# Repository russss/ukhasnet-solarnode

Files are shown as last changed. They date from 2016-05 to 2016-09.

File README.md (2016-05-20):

# UKHASnet SolarNode

A [ukhasnet node](https://ukhas.net) implementation designed for use as
a remote, solar/lithium battery-powered repeater.

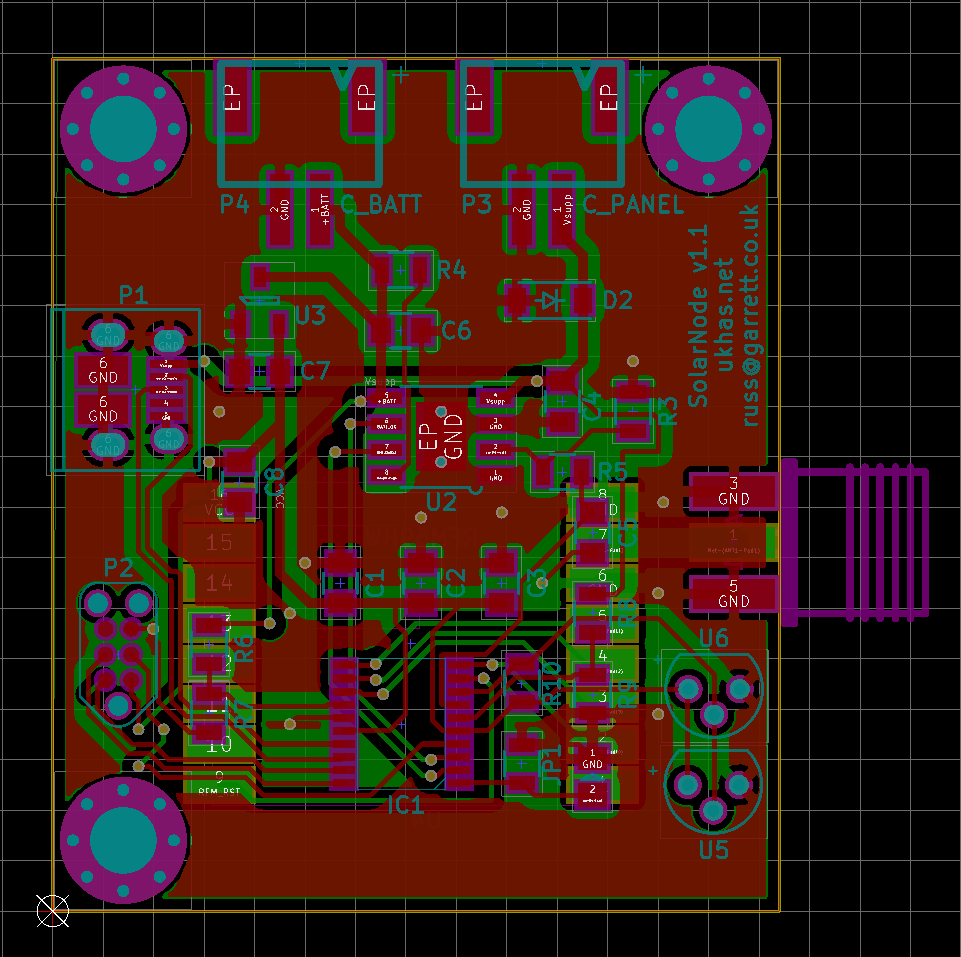
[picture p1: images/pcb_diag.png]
PCB layout


## Features

* STM32 ARM micoprocessor
* CN3083 Li-Ion charge controller
* RFM89[H][W] radio
* Charging and configuration over USB
* Comprehensive battery telemetry:
    * Supply (solar panel) voltage
    * Battery voltage
    * Charge current
    * Charger status
* Breakout for one-wire sensors

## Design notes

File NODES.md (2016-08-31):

* 1: Initial dev board, RFM69W. CN3083 potentially damaged by
     overvolting.
* 2: RFM69HW.

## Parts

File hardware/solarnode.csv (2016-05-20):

Reference | Value | Footprint | Datasheet | Farnell
P2 | TC2030-CTX | Tag-Connect:TC2030-NL_SMALL
U4 | RFM69HW | tinkerforge:RFM69HW
ANT1 | ANT | tinkerforge:CON-SMA-EDGE
P1 | USB_OTG | Connect:USB_Micro-B_10103594-0001LF
P3 | C_PANEL | tinkerforge:JST-PH-2
P4 | C_BATT | tinkerforge:JST-PH-2
D2 | 6V | Diodes_SMD:SOD-123
R8 | 10k | Resistors_SMD:R_0805
R9 | 10k | Resistors_SMD:R_0805
C4 | 22u | Capacitors_SMD:C_0805
R3 | 3k6 | Resistors_SMD:R_0805
R5 | 10k | Resistors_SMD:R_0805
C5 | C | Capacitors_SMD:C_0805
R4 | 0 | Resistors_SMD:R_0805
U3 | MCP1700 | agg:SOT-23
C7 | 1u | Capacitors_SMD:C_0805
R6 | 4k7 | Resistors_SMD:R_0805
R7 | 10k | Resistors_SMD:R_0805
R10 | 4k7 | Resistors_SMD:R_0805
C8 | 100n | Capacitors_SMD:C_0805
C2 | 100n | Capacitors_SMD:C_0805
C3 | 100n | Capacitors_SMD:C_0805
C1 | 4.7u | Capacitors_SMD:C_0805
JP1 | Boot | Resistors_SMD:R_0805
D1 | Status | agg:0805-LED
U5 | DS18B20 | TO_SOT_Packages_THT:TO-92_Molded_Narrow
U6 | DS18B20 | TO_SOT_Packages_THT:TO-92_Molded_Narrow
C6 | 4.7u | Capacitors_SMD:C_0805
IC1 | STM32F0xxFxPx | tinkerforge:TSSOP20 | http://www.st.com/st-web-ui/static/active/en/resource/technical/document/datasheet/DM00105814.pdf | 2469549
U2 | CN3083 | agg:SOIC-8-EP-CN

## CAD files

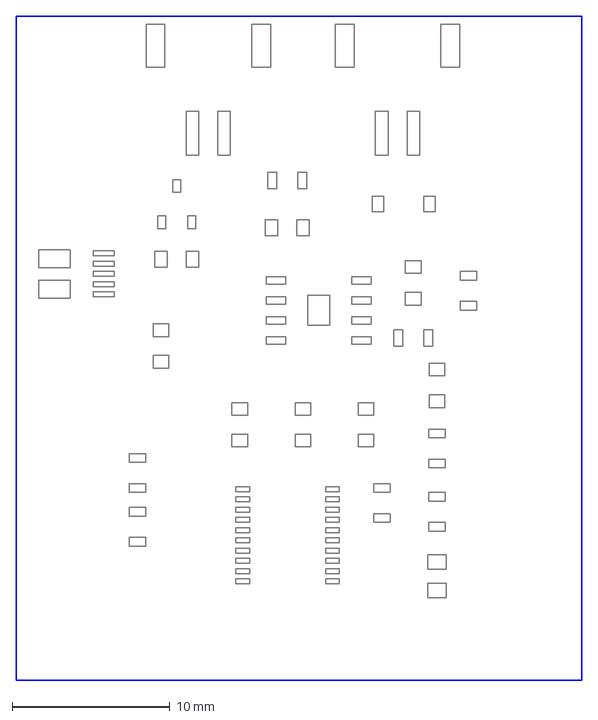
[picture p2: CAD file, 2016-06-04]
hardware/stencil.dxf
35.8 x 42.1 mm

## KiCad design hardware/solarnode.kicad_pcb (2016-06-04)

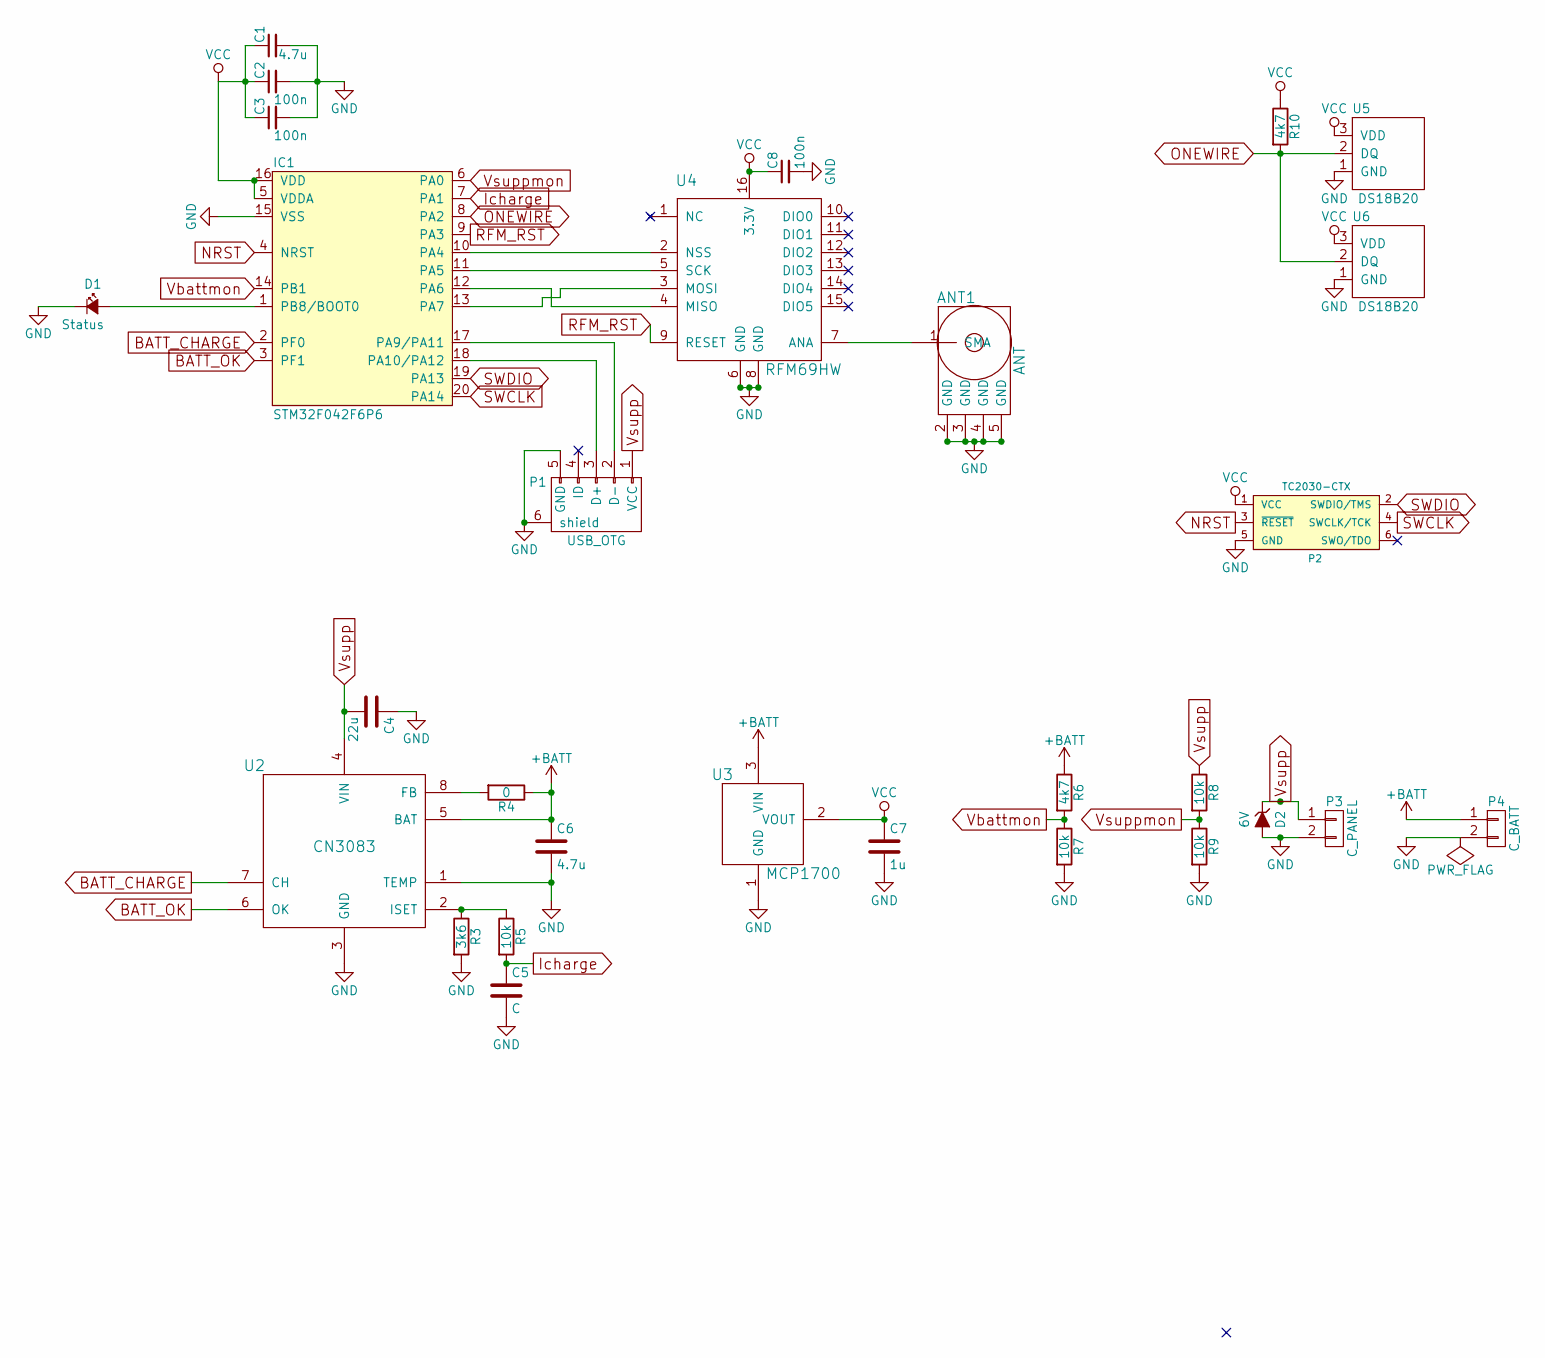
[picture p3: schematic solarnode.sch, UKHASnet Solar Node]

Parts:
ANT1: ANT; CON-SMA-EDGE
C1, C6: 4.7u; C_0805
C2, C3, C8: 100n; C_0805
C4: 22u; C_0805
C5: C; C_0805
C7: 1u; C_0805
D1: Status; 0805-LED
D2: 6V; SOD-123
IC1: STM32F042F6P6; TSSOP20; Farnell 2469549
P1: USB_OTG; USB_Micro-B_10103594-0001LF
P2: TC2030-CTX; TC2030-NL_SMALL
P3: C_PANEL; JST-PH-2
P4: C_BATT; JST-PH-2
R3: 3k6; R_0805
R4: 0; R_0805
R5, R7, R8, R9: 10k; R_0805
R6, R10: 4k7; R_0805
U2: CN3083; SOIC-8-EP-CN
U3: MCP1700; SOT-23
U4: RFM69HW
U5, U6: DS18B20; TO-92_Molded_Narrow

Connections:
+BATT: C6.1, P4.1, R4.1, R6.1, U2.5 (BAT), U3.3 (VIN)
BATT_CHARGE: IC1.2 (PF0), U2.7 (CH)
BATT_OK: IC1.3 (PF1), U2.6 (OK)
GND: ANT1.2 (GND), ANT1.3 (GND), ANT1.4 (GND), ANT1.5 (GND), C1.2, C2.2, C3.2, C4.1, C5.2, C6.2, C7.2, C8.2, D1.1 (K), D2.2 (A), IC1.15 (VSS), P1.5 (GND), P1.6 (shield), P2.5 (GND), P3.2, P4.2, R3.2, R7.2, R9.2, U2.1 (TEMP), U2.3 (GND), U2.EP, U3.1 (GND), U4.6 (GND), U4.8 (GND), U5.1 (GND), U6.1 (GND)
Icharge: C5.1, IC1.7 (PA1), R5.2
NRST: IC1.4 (NRST), P2.3 (~RESET~)
unnamed: ANT1.1 (SMA), U4.7 (ANA)
unnamed: D1.2 (A), IC1.1 (PB8/BOOT0)
unnamed: IC1.10 (PA4), U4.2 (NSS)
unnamed: IC1.11 (PA5), U4.5 (SCK)
unnamed: IC1.12 (PA6), U4.4 (MISO)
unnamed: IC1.13 (PA7), U4.3 (MOSI)
unnamed: IC1.17 (PA9/PA11), P1.2 (D-)
unnamed: IC1.18 (PA10/PA12), P1.3 (D+)
unnamed: R3.1, R5.1, U2.2 (ISET)
unnamed: R4.2, U2.8 (FB)
ONEWIRE: IC1.8 (PA2), R10.2, U5.2 (DQ), U6.2 (DQ)
RFM_RST: IC1.9 (PA3), U4.9 (RESET)
SWCLK: IC1.20 (PA14), P2.4 (SWCLK/TCK)
SWDIO: IC1.19 (PA13), P2.2 (SWDIO/TMS)
VCC: C1.1, C2.1, C3.1, C7.1, C8.1, IC1.5 (VDDA), IC1.16 (VDD), P2.1 (VCC), R10.1, U3.2 (VOUT), U4.16 (3.3V), U5.3 (VDD), U6.3 (VDD)
Vbattmon: IC1.14 (PB1), R6.2, R7.1
Vsupp: C4.2, D2.1 (K), P1.1 (VCC), P3.1, R8.1, U2.4 (VIN)
Vsuppmon: IC1.6 (PA0), R8.2, R9.1

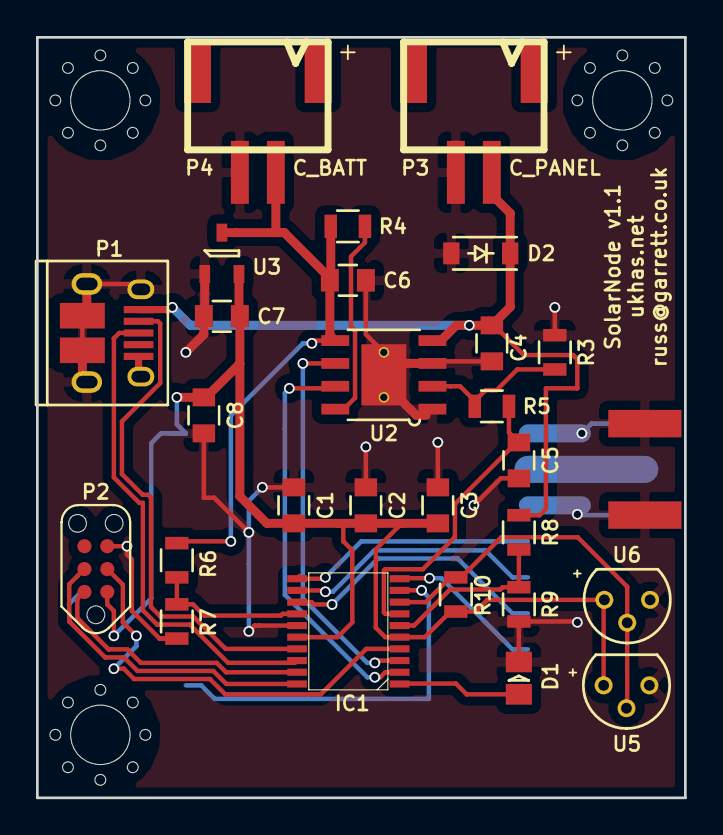
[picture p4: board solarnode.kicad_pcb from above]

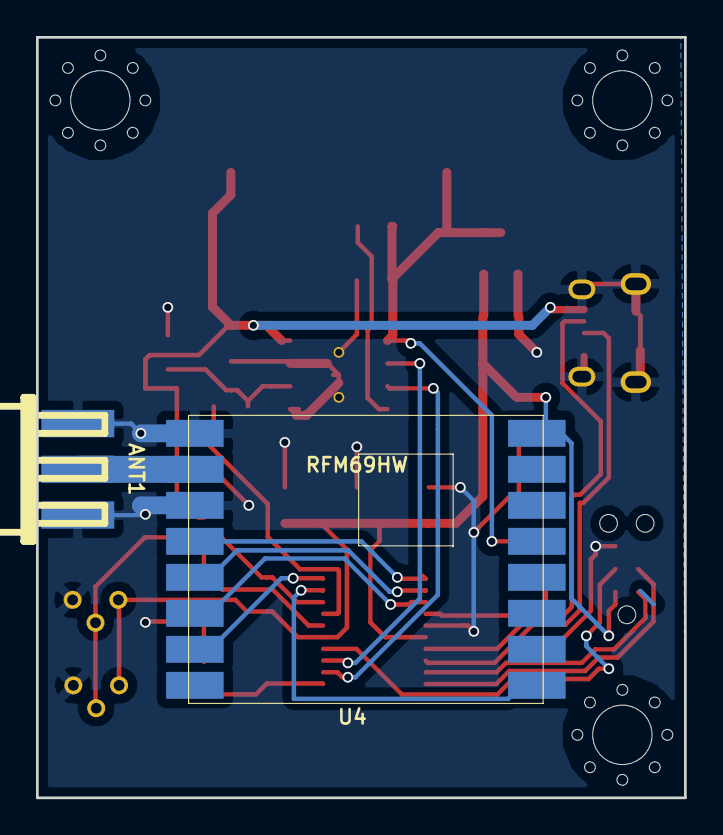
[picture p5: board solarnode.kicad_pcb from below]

Board: 2 copper layers, 36.0 x 42.2 mm, 29 parts (2 on the bottom side), 24 nets.

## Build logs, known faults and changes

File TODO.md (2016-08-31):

TODO for hardware version 2:

* Lose the zener, it's not useful
* Insert 6V LDO regulator to protect CN3083 input
* Replace 3.3V regulator with one which has UVLO.
  (Lithiums provide little useful power below 3.3V anyway)

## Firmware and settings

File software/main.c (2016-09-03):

#include <string.h>
#include "ch.h"
#include "hal.h"
#include "test.h"
#include "chprintf.h"
#include "shell.h"

#include "solarnode_usb.h"
#include "solarnode_shell.h"
#include "solarnode_config.h"
#include "solarnode_rfm69.h"
#include "solarnode_onewire.h"
#include "solarnode_led.h"
#include "solarnode_ukhasnet.h"

// Configure watchdog: 1000 * 64 / 40kHz = 1.6 seconds
static const WDGConfig wdgcfg = {
  STM32_IWDG_PR_64,
  STM32_IWDG_RL(1000),
  STM32_IWDG_WIN_DISABLED
};

static void hardware_config(void) {
    // Remap pins PA11 and PA12 to enable USB
    SYSCFG->CFGR1 |= SYSCFG_CFGR1_PA11_PA12_RMP;
    // Stop watchdog when core is halted for debugging
    DBGMCU->APB1FZ |= DBGMCU_APB1_FZ_DBG_IWDG_STOP;
}

static void jump_to_bootloader(void) {
    SYSCFG->CFGR1 = 0x01;
    __set_MSP(*((uint32_t*) 0x00000000));
    ((void (*)(void)) *((uint32_t*) 0x00000004))();
    while (1);
}

int main(void) {
    if (RTC->BKP0R == 0x42) {
        jump_to_bootloader();
    }
    halInit();
    chSysInit();
    hardware_config();
    ledInit();
    ConfigInit();
    USBInit();
    shellInit();
    oneWireInit();
    rfm69Init();
    ukhasnetInit();
#ifndef _DEBUG
    wdgStart(&WDGD1, &wdgcfg);
#endif

    while (true) {
        checkShell();
        chThdSleepMilliseconds(1000);
#ifndef _DEBUG
        wdgReset(&WDGD1);
#endif
    }
}

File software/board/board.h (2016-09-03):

/*
    ChibiOS - Copyright (C) 2006..2015 Giovanni Di Sirio

    Licensed under the Apache License, Version 2.0 (the "License");
    you may not use this file except in compliance with the License.
    You may obtain a copy of the License at

        http://www.apache.org/licenses/LICENSE-2.0

    Unless required by applicable law or agreed to in writing, software
    distributed under the License is distributed on an "AS IS" BASIS,
    WITHOUT WARRANTIES OR CONDITIONS OF ANY KIND, either express or implied.
    See the License for the specific language governing permissions and
    limitations under the License.
*/

#ifndef _BOARD_H_
#define _BOARD_H_

/*
 * Board identifier.
 */
#define BOARD_UKHASNET_SOLARNODE
#define BOARD_NAME                  "UKHASnet SolarNode"

/*
 * Board oscillators-related settings.
 * NOTE: LSE not fitted.
 * NOTE: HSE not fitted.
 */
#if !defined(STM32_LSECLK)
#define STM32_LSECLK                0U
#endif

#define STM32_LSEDRV                (3U << 3U)

#if !defined(STM32_HSECLK)
#define STM32_HSECLK                0U
#endif

/*
 * MCU type as defined in the ST header.
 */
#define STM32F042x6

/*
 * IO pins assignments.
 */
#define GPIOA_VSUPPMON              0U
#define GPIOA_ICHARGE               1U
#define GPIOA_ONEWIRE               2U
#define GPIOA_RFM_RST               3U
#define GPIOA_NSS                   4U
#define GPIOA_SCK                   5U
#define GPIOA_MISO                  6U
#define GPIOA_MOSI                  7U
#define GPIOA_ARD_D9                8U
#define GPIOA_ARD_D1                9U
#define GPIOA_ARD_D0                10U
#define GPIOA_ARD_D10               11U
#define GPIOA_ARD_D2                12U
#define GPIOA_SWDIO                 13U
#define GPIOA_SWCLK                 14U
#define GPIOA_VCP_RX                15U

#define GPIOB_ARD_D3                0U
#define GPIOB_ARD_D6                1U
#define GPIOB_PIN2                  2U
#define GPIOB_ARD_D13               3U
#define GPIOB_ARD_D12               4U
#define GPIOB_ARD_D11               5U
#define GPIOB_ARD_D5                6U
#define GPIOB_ARD_A5_ALT            6U
#define GPIOB_ARD_D4                7U
#define GPIOB_ARD_A4_ALT            7U
#define GPIOB_LED                   8U
#define GPIOB_PIN9                  9U
#define GPIOB_PIN10                 10U
#define GPIOB_PIN11                 11U
#define GPIOB_PIN12                 12U
#define GPIOB_PIN13                 13U
#define GPIOB_PIN14                 14U
#define GPIOB_PIN15                 15U

#define GPIOC_PIN0                  0U
#define GPIOC_PIN1                  1U
#define GPIOC_PIN2                  2U
#define GPIOC_PIN3                  3U
#define GPIOC_PIN4                  4U
#define GPIOC_PIN5                  5U
#define GPIOC_PIN6                  6U
#define GPIOC_PIN7                  7U
#define GPIOC_PIN8                  8U
#define GPIOC_PIN9                  9U
#define GPIOC_PIN10                 10U
#define GPIOC_PIN11                 11U
#define GPIOC_PIN12                 12U
#define GPIOC_PIN13                 13U
#define GPIOC_PIN14                 14U
#define GPIOC_PIN15                 15U

#define GPIOD_PIN0                  0U
#define GPIOD_PIN1                  1U
#define GPIOD_PIN2                  2U
#define GPIOD_PIN3                  3U
#define GPIOD_PIN4                  4U
#define GPIOD_PIN5                  5U
#define GPIOD_PIN6                  6U
#define GPIOD_PIN7                  7U
#define GPIOD_PIN8                  8U
#define GPIOD_PIN9                  9U
#define GPIOD_PIN10                 10U
#define GPIOD_PIN11                 11U
#define GPIOD_PIN12                 12U
#define GPIOD_PIN13                 13U
#define GPIOD_PIN14                 14U
#define GPIOD_PIN15                 15U

#define GPIOE_PIN0                  0U
#define GPIOE_PIN1                  1U
#define GPIOE_PIN2                  2U
#define GPIOE_PIN3                  3U
#define GPIOE_PIN4                  4U
#define GPIOE_PIN5                  5U
#define GPIOE_PIN6                  6U
#define GPIOE_PIN7                  7U
#define GPIOE_PIN8                  8U
#define GPIOE_PIN9                  9U
#define GPIOE_PIN10                 10U
#define GPIOE_PIN11                 11U
#define GPIOE_PIN12                 12U
#define GPIOE_PIN13                 13U
#define GPIOE_PIN14                 14U
#define GPIOE_PIN15                 15U
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

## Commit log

2016-04-17 Initial hardware design
    [solarnode.kicad_pcb, solarnode.sch]
2016-04-17 BOM CSV
    [solarnode.csv]
2016-04-17 Fix open-drain pull-ups to be actual pull-ups
    [solarnode.kicad_pcb, solarnode.sch]
2016-05-19 Reduce stack size. Fix inverted charge/OK.
    [solarnode_shell.c]
2016-05-20 v1.0 Stencil
    [stencil.dxf]
2016-05-20 Version 1.1
    - Fix incorrect RFM69 SPI wiring
    - Remove unneeded pullup resistors on CN3083 open-drain outputs
    - Fix silk text sizing so it's actually readable
    [solarnode.kicad_pcb, solarnode.sch]
2016-05-20 Add PCB layout to readme
2016-05-20 Update BOM for version 1.1
    [solarnode.csv]
2016-05-20 Remove unneeded boot jumper
    [solarnode.sch]
2016-05-29 Include onewire driver directly
2016-06-04 Board config tweaks
2016-06-04 Initial RFM69 driver
2016-06-04 Version 1.1 hardware + stencil
    [solarnode.kicad_pcb, stencil.dxf]
2016-06-05 Allocate shell thread statically
2016-06-05 LED blinker thread
2016-06-08 Current (broken) RFM69 state
    [solarnode_led.c, solarnode_rfm69.c, solarnode_shell.c]
2016-06-11 Pack charge status into one byte
2016-06-11 Fix zombie logic bug
    [solarnode_ukhasnet.c]
2016-06-12 Initial output power setting logic
2016-06-13 Use 2 decimal places for all voltages
2016-06-15 Increase default low battery voltage to 3.9V
2016-06-15 Increase max USB power to 512mA to reflect charge current
2016-06-16 Working 1-wire temperature reading
2016-06-16 Add 1-wire retry logic
    because the 1-wire implementation is not bulletproof
2016-06-18 RFM69 high-power settings and tweaks
2016-09-03 Fix prototype
2016-09-03 DFU upgrade from USB (not working)
    [main.c, solarnode_shell.c]
2016-09-03 Better error checking in shell
    [solarnode_shell.c]
2016-09-12 Format RSSI threshold correctly
    [solarnode_ukhasnet.c]
